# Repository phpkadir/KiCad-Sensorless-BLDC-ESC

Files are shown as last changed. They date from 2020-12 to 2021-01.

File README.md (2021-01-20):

# KiCad-Sensorless-BLDC-ESC

I designed this pcb because I want to be able to try different microcontrollers as part of Electronic Speed Controller projects. It can be used with especially the microcontrollers those don't have the internal comparator capability.

I ordered the version 0.3 and will test it when it arrives.

I made some mistakes about connections of the mosfet circuits. I will fix those mistakes in the next update.

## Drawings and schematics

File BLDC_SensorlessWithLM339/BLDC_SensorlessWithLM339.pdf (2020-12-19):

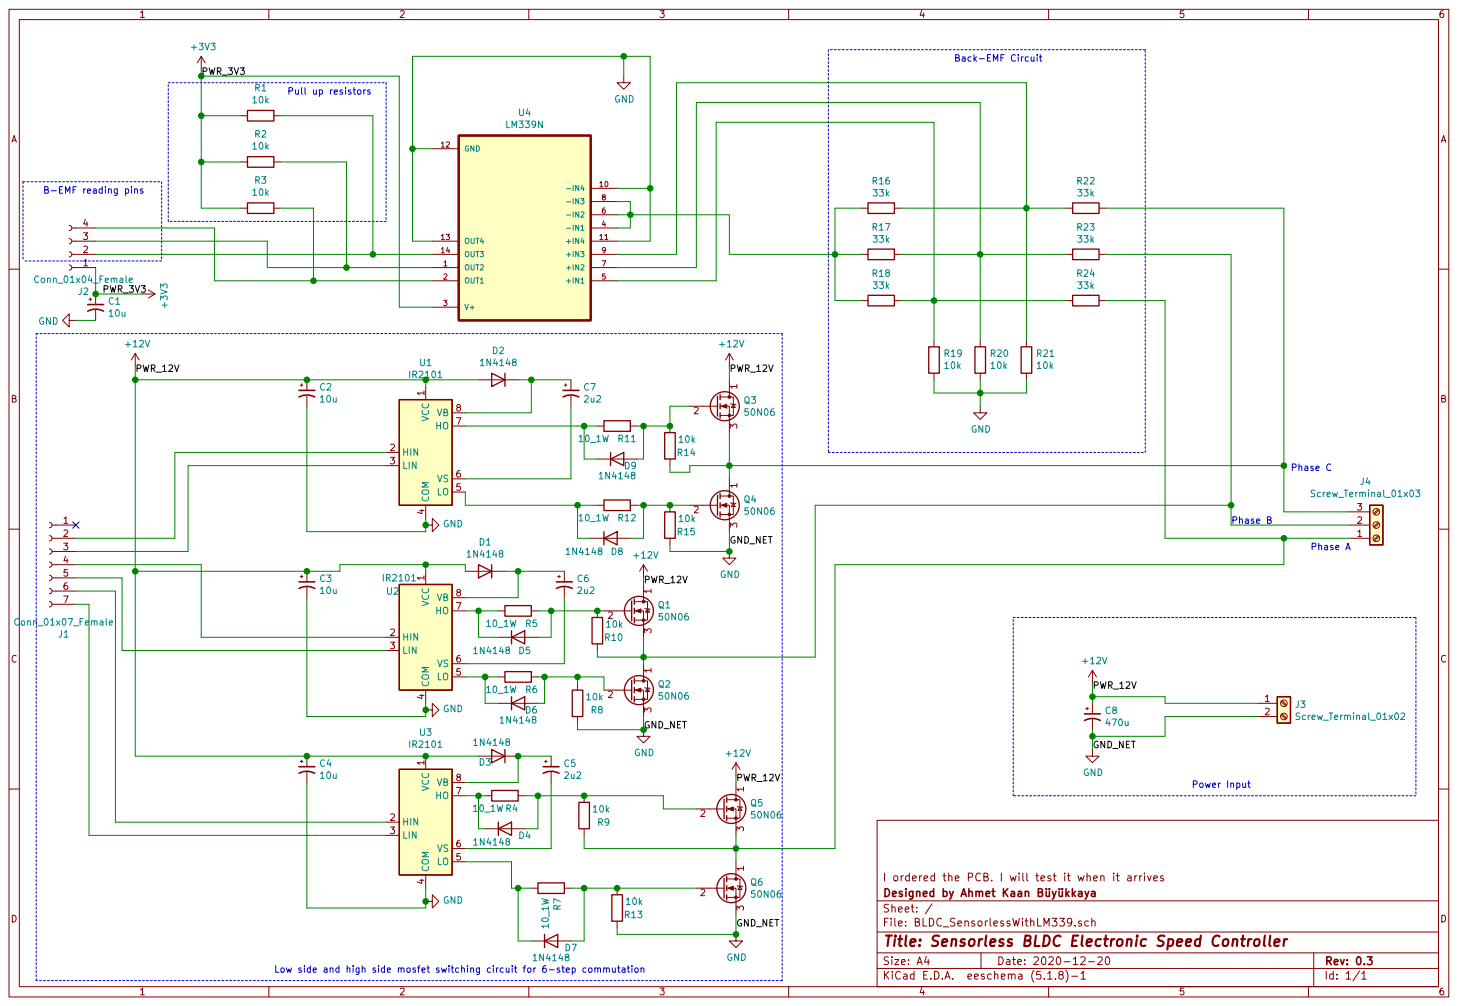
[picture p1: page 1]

1 HIN 2
I ordered the PCB. I will test it when it arrives VCC

File: BLDC_SensorlessWithLM339.sch Sheet: / Designed by Ahmet Kaan Büyükkaya

Id: 1/1 Title: Sensorless BLDC Electronic Speed Controller

Low side and high side mosfet switching circuit for 6-step commutation

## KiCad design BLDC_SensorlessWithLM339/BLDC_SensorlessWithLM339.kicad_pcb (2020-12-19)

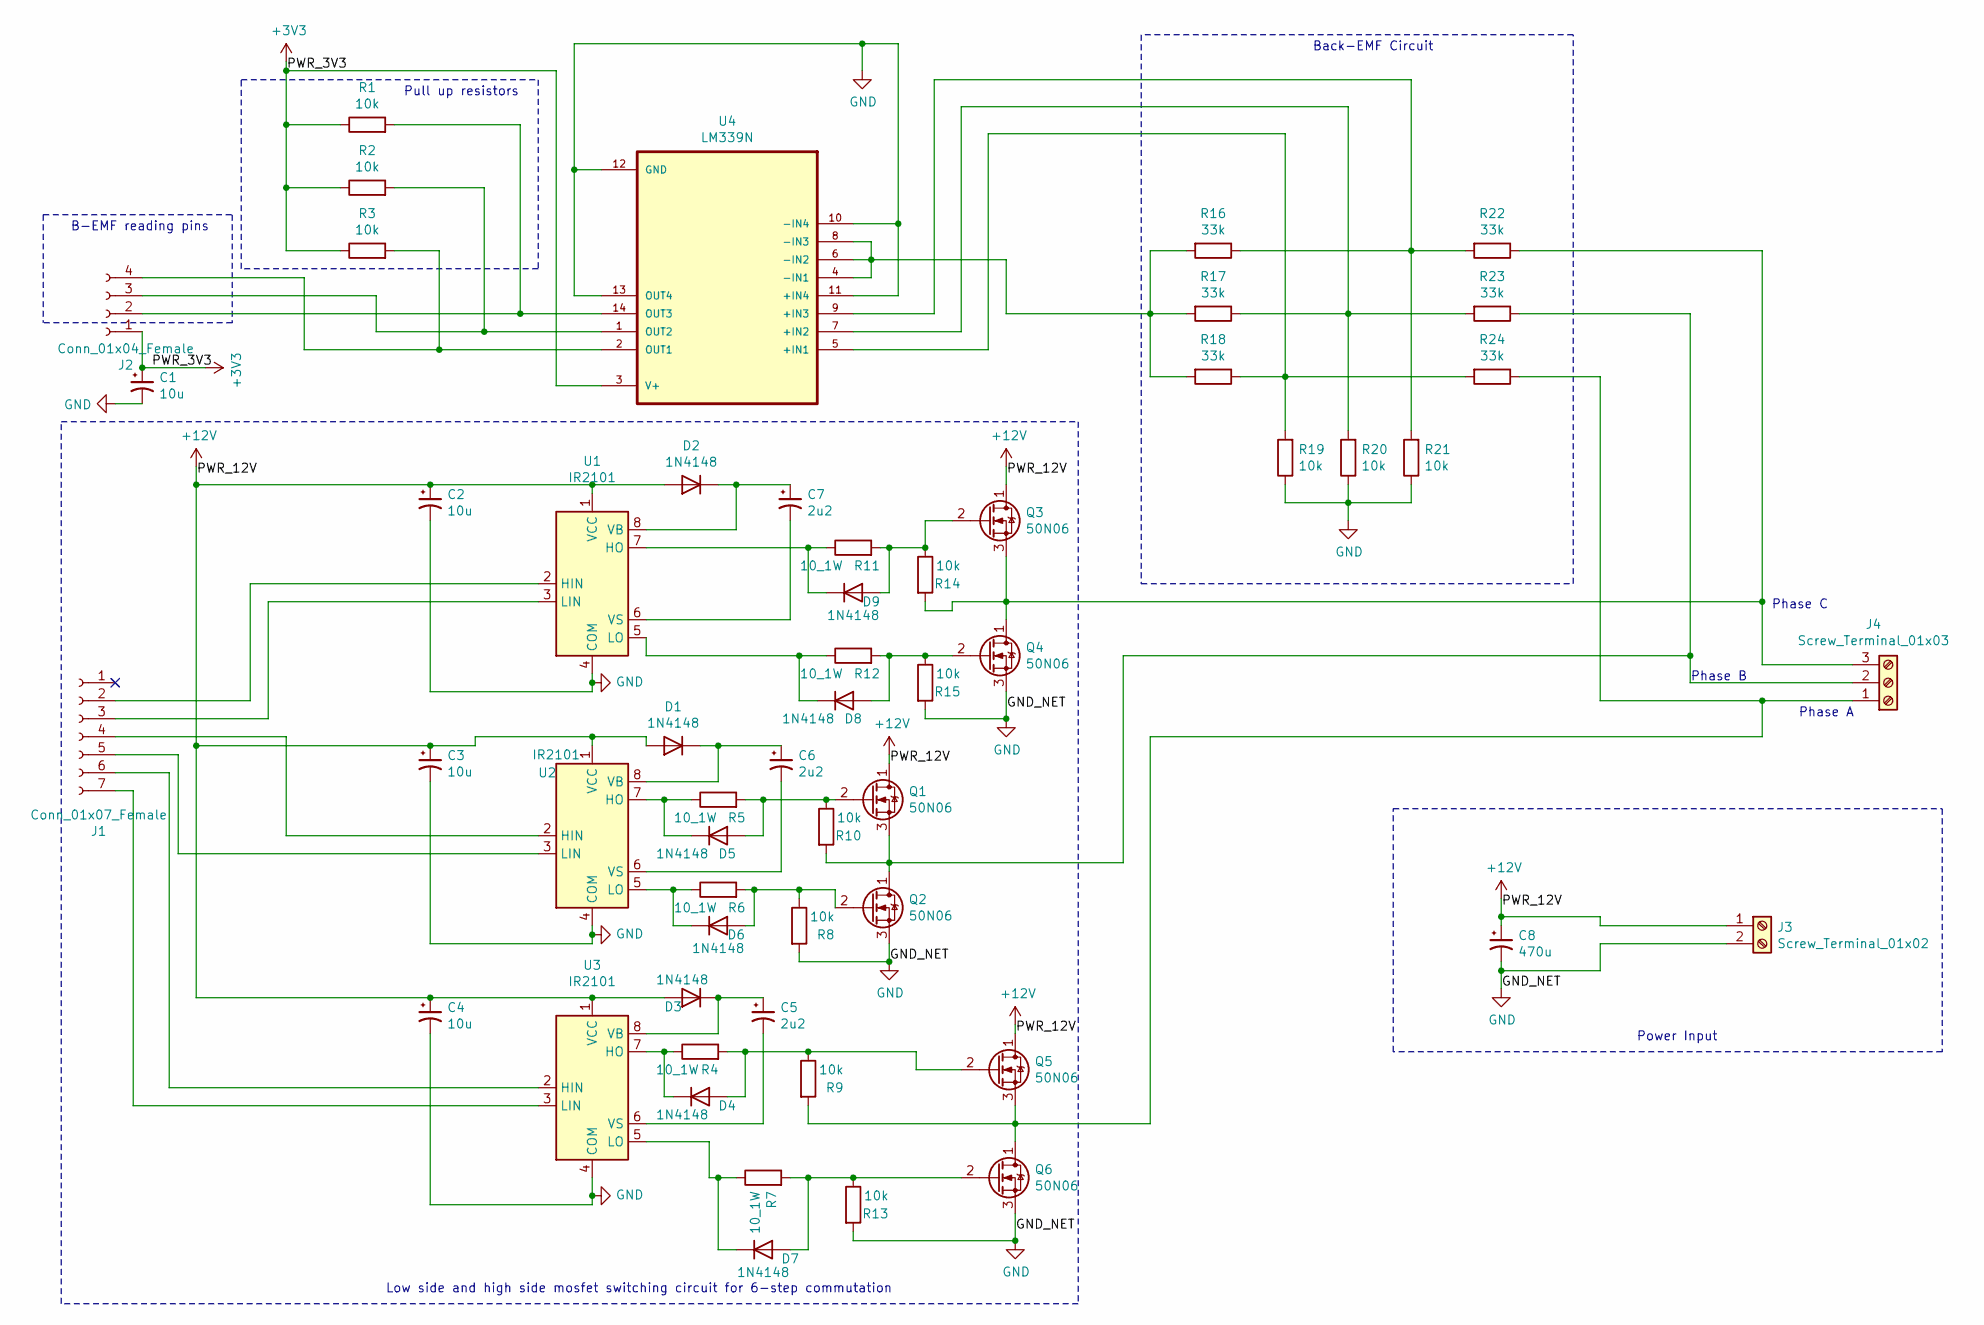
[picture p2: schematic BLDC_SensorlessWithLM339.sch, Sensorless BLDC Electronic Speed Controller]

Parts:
C1, C2, C3, C4: 10u; CP_Radial_D5.0mm_P2.50mm
C5, C6, C7: 2u2; CP_Radial_D5.0mm_P2.50mm
C8: 470u; CP_Radial_D10.0mm_P5.00mm
D1, D2, D3, D4, D5, D6, D7, D8, D9: 1N4148; D_DO-35_SOD27_P7.62mm_Horizontal
J1: Conn_01x07_Female; PinSocket_1x07_P2.54mm_Vertical
J2: Conn_01x04_Female; PinSocket_1x04_P2.54mm_Vertical
J3: Screw_Terminal_01x02; TerminalBlock_bornier-2_P5.08mm
J4: Screw_Terminal_01x03; TerminalBlock_bornier-3_P5.08mm
Q1, Q2, Q3, Q4, Q5, Q6: 50N06; TO-220-3_Vertical
R1, R2, R3, R8, R9, R10, R13, R14, R15, R19, R20, R21: 10k; R_0805_2012Metric_Pad1.20x1.40mm_HandSolder
R4, R5, R6, R7, R11, R12: 10_1W; R_2512_6332Metric_Pad1.40x3.35mm_HandSolder
R16, R17, R18, R22, R23, R24: 33k; R_0805_2012Metric_Pad1.20x1.40mm_HandSolder
U1, U2, U3: IR2101; DIP-8_W7.62mm_LongPads
U4: LM339N; DIP794W45P254L1969H508Q14

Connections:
+3V3: C1.1, J2.1, R1.1, R2.1, R3.1, U4.3 (V+)
+12V: C2.1, C3.1, C4.1, C8.1, D1.2 (A), D2.2 (A), D3.2 (A), J3.1, Q1.1 (D), Q3.1 (D), Q5.1 (D), U1.1 (VCC), U2.1 (VCC), U3.1 (VCC)
GND: C1.2, C2.2, C3.2, C4.2, C8.2, J3.2, Q2.3 (S), Q4.3 (S), Q6.3 (S), R8.2, R13.2, R15.2, R19.1, R20.1, R21.1, U1.4 (COM), U2.4 (COM), U3.4 (COM), U4.10 (-IN4), U4.11 (+IN4), U4.12 (GND), U4.13 (OUT4)
unnamed: C5.1, D3.1 (K), U3.8 (VB)
unnamed: C5.2, U3.6 (VS)
unnamed: C6.1, D1.1 (K), U2.8 (VB)
unnamed: C6.2, U2.6 (VS)
unnamed: C7.1, D2.1 (K), U1.8 (VB)
unnamed: C7.2, U1.6 (VS)
unnamed: D4.1 (K), R4.1, U3.7 (HO)
unnamed: D4.2 (A), Q5.2 (G), R4.2, R9.1
unnamed: D5.1 (K), R5.1, U2.7 (HO)
unnamed: D5.2 (A), Q1.2 (G), R5.2, R10.1
unnamed: D6.1 (K), R6.1, U2.5 (LO)
unnamed: D6.2 (A), Q2.2 (G), R6.2, R8.1
unnamed: D7.1 (K), R7.1, U3.5 (LO)
unnamed: D7.2 (A), Q6.2 (G), R7.2, R13.1
unnamed: D8.1 (K), R12.1, U1.5 (LO)
unnamed: D8.2 (A), Q4.2 (G), R12.2, R15.1
unnamed: D9.1 (K), R11.1, U1.7 (HO)
unnamed: D9.2 (A), Q3.2 (G), R11.2, R14.1
unnamed: J1.2, U1.2 (HIN)
unnamed: J1.3, U1.3 (LIN)
unnamed: J1.4, U2.2 (HIN)
unnamed: J1.5, U2.3 (LIN)
unnamed: J1.6, U3.2 (HIN)
unnamed: J1.7, U3.3 (LIN)
unnamed: J2.2, R1.2, U4.14 (OUT3)
unnamed: J2.3, R2.2, U4.1 (OUT2)
unnamed: J2.4, R3.2, U4.2 (OUT1)
unnamed: J4.1, Q5.3 (S), Q6.1 (D), R9.2, R24.1
unnamed: J4.2, Q1.3 (S), Q2.1 (D), R10.2, R23.1
unnamed: J4.3, Q3.3 (S), Q4.1 (D), R14.2, R22.1
unnamed: R16.1, R21.2, R22.2, U4.9 (+IN3)
unnamed: R16.2, R17.2, R18.2, U4.4 (-IN1), U4.6 (-IN2), U4.8 (-IN3)
unnamed: R17.1, R20.2, R23.2, U4.7 (+IN2)
unnamed: R18.1, R19.2, R24.2, U4.5 (+IN1)

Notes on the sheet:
Low side and high side mosfet switching circuit for 6-step commutation
Back-EMF Circuit
Phase A
Phase B
Phase C
Power Input
Pull up resistors
B-EMF reading pins

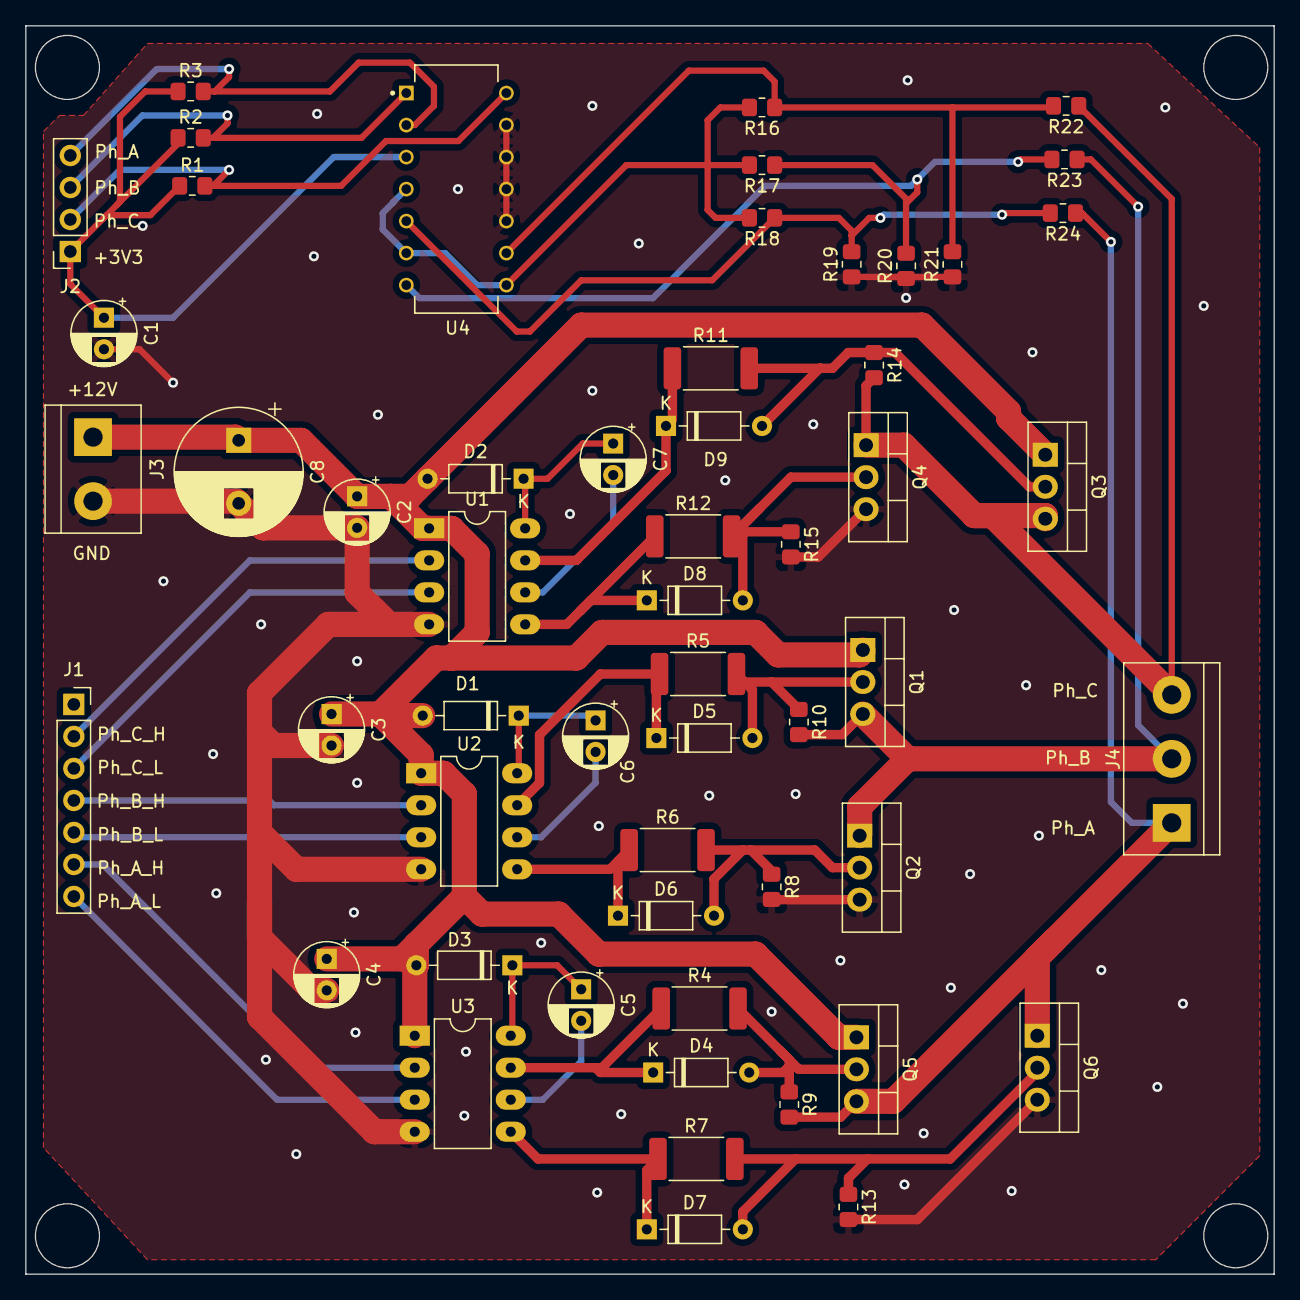
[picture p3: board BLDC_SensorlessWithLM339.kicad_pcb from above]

Board: 2 copper layers, 99.1 x 99.1 mm, 55 parts (0 on the bottom side), 37 nets.

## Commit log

2020-12-10 Versin 0.1
    Version 0.1
    [BLDC_SensorlessWithLM339.kicad_pcb, BLDC_SensorlessWithLM339.sch]
2020-12-14 Updated to Version 0.2
    Updated to version 0.2. Now pcb holds only 10x10 cm^2 field.
    [BLDC_SensorlessWithLM339.kicad_pcb, BLDC_SensorlessWithLM339.sch]
2020-12-14 Updated to version 0.2
    PCB holds only 10x10 cm^2 field now. I need to test it.
    [BLDC_SensorlessWithLM339.kicad_pcb, BLDC_SensorlessWithLM339.sch]
2020-12-19 Version 0.3
    I ordered the PCB. I will test it when it arrives.
    [BLDC_SensorlessWithLM339-B_Cu.gbl, BLDC_SensorlessWithLM339-B_Mask.gbs, BLDC_SensorlessWithLM339-B_Paste.gbp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]
